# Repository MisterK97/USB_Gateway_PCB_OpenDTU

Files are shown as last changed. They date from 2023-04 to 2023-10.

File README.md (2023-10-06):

# USB-Gateway-Platine für z.B. OpenDTU auf ESP32-Basis

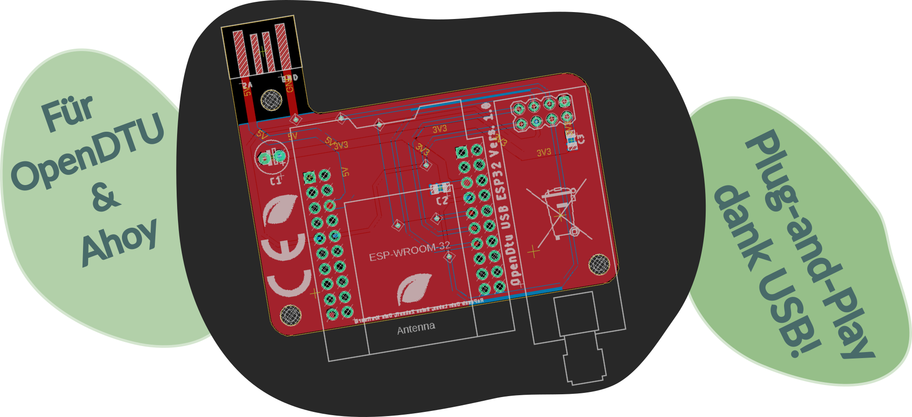
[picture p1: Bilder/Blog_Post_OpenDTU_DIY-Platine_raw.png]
Layout der USB-Gateway-Platine


In diesem Repo werden die Unterlagen und Dateien zum USB-Gateway abgelegt.

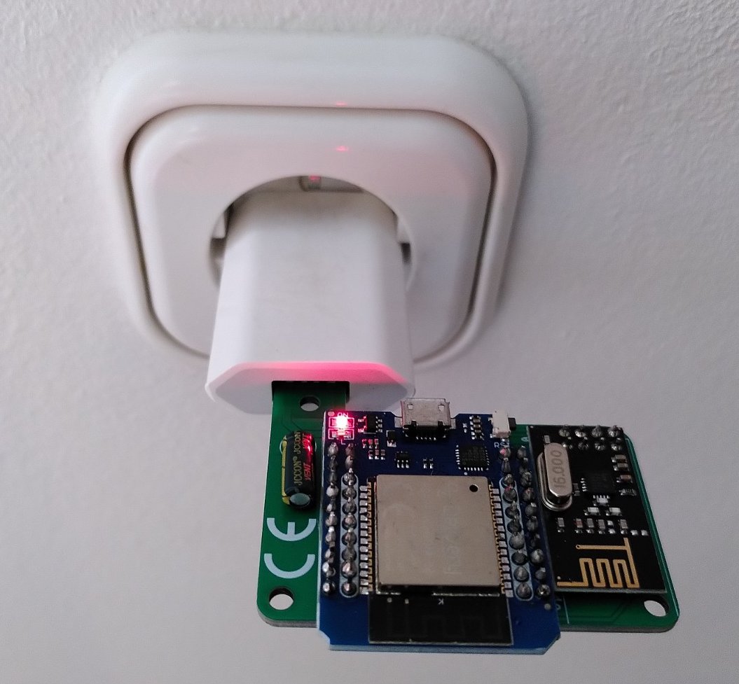
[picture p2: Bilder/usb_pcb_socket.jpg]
USB-Gateway-Platine in Steckdose

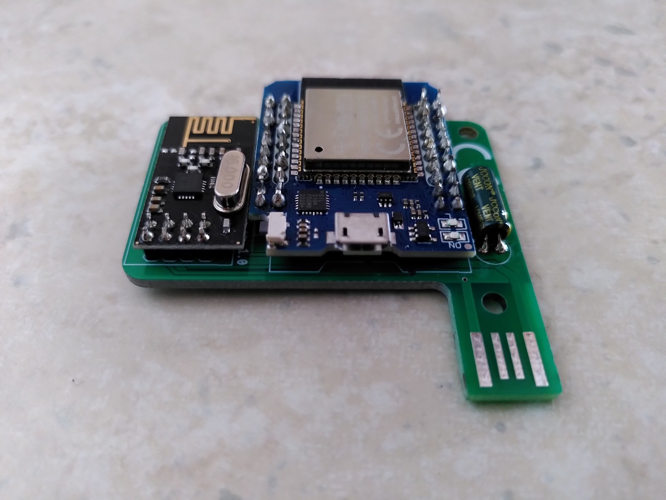
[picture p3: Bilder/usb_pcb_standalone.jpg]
USB-Gateway-Platine


Die Platine wurde mit Eagle entworfen und auf Basis des Schaltplans der Github-Page von OpenDTU (<https://github.com/tbnobody/OpenDTU>) erstellt.
Mit der besonderen Form der Platine kann das Gateway direkt über ein USB-Netzteil versorgt werden und benötigt daher kein Kabel oder eine zusätzliche Befestigung.

Wenn man die Platine fertigt gelötet hat und den ESP32 mit OpenDTU geflasht hat, müssen keine zusätzlichen Einstellungen bezüglich der GPIOs vorgenommen werden.
Die Pin-Belegung entspricht der Standardbelegung von OpenDTU.

**Schaltplan-Ausschnitt und Layout:**
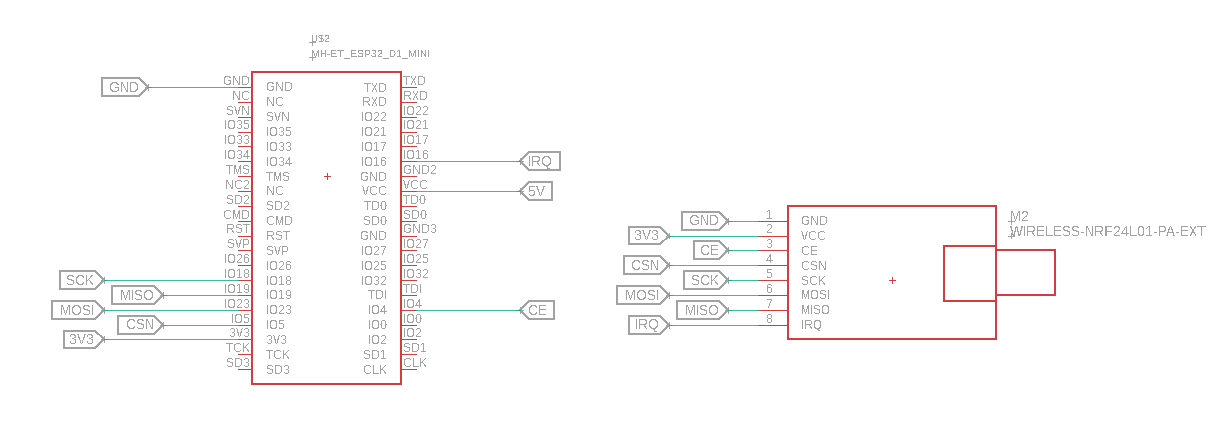
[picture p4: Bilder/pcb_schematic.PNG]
USB-Gateway-Schaltplan

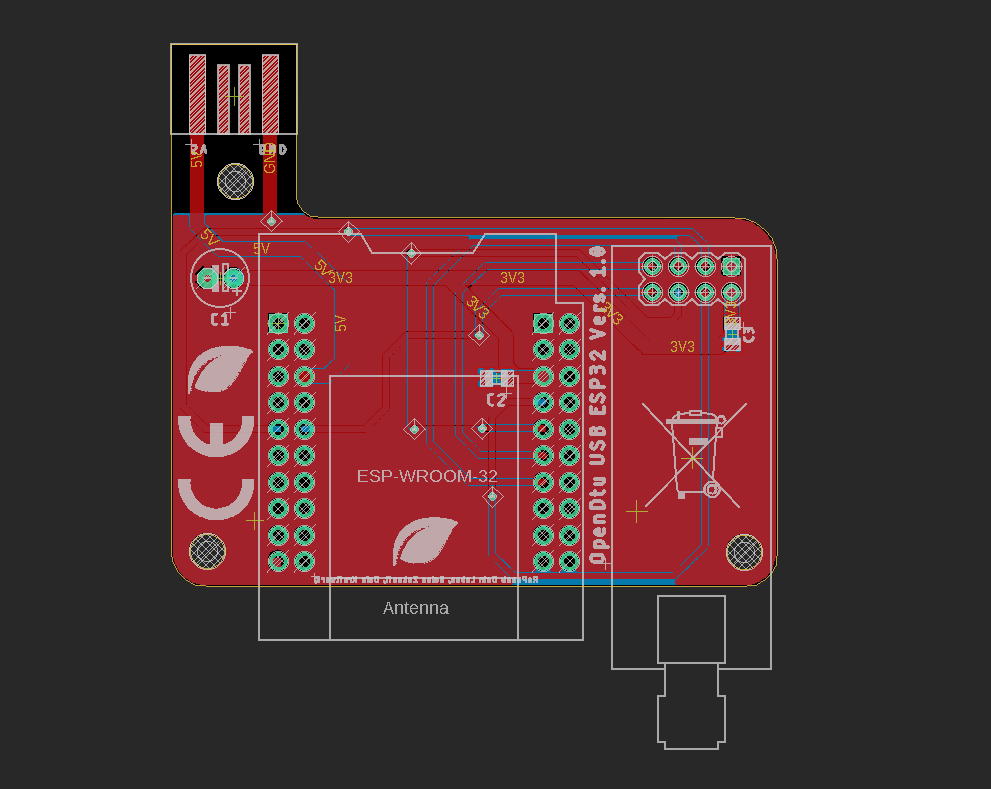
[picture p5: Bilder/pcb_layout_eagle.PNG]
USB-Gateway-Layout


**Benötigte Komponenten:**
- USB-Platine (siehe Dateien)
- ESP32 D1 MINI (<https://www.azdelivery.de/products/esp32-d1-mini>)
- NRF24L01 (<https://www.azdelivery.de/products/3x-nrf24l01-mit-2-4-ghz>)

Diese Repo hat nichts mit der OpenDTU-Repo (<https://github.com/tbnobody/OpenDTU>) zu tun und steht in keiner Absprache mit den Entwickler*innen. Danke für die tolle Arbeit der Community! Ich hoffe meine kleine Platine hilft euch!

Die Verwendung der gezeigten Platine bzw. des Schaltplanes erfolgt auf eigenes Risiko und ohne jegliche Gewährleistung!

Viel Spaß beim Modifizieren und Basteln! :)

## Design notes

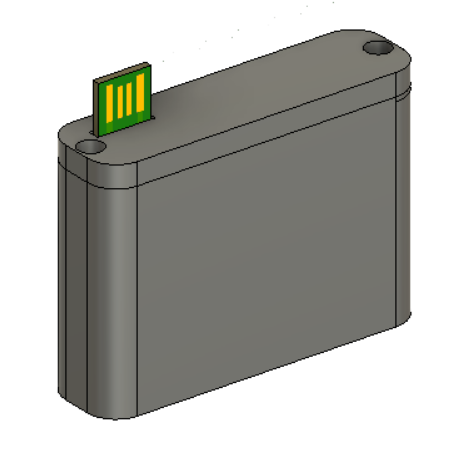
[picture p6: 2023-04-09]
Bilder/pcb_case_fusion360.PNG

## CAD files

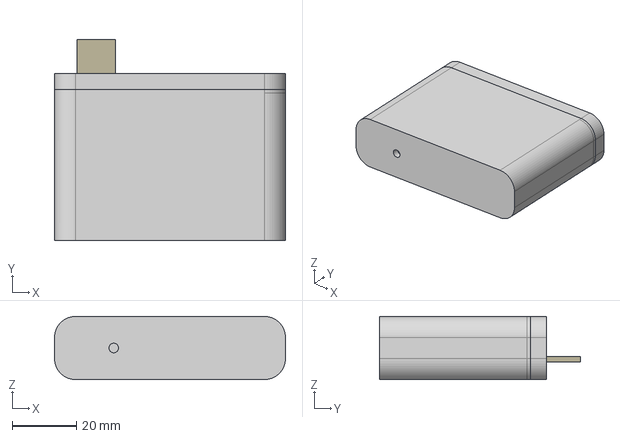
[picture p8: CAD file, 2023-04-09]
CAD/USB-Gateway_Case.step
72.1 x 62.8 x 19.7 mm

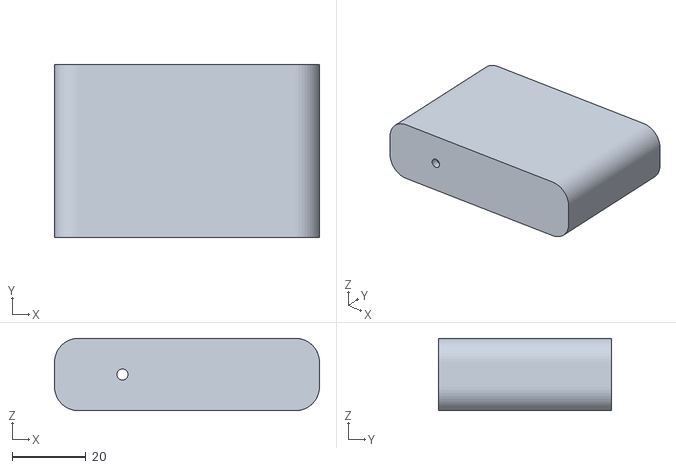
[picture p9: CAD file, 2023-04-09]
CAD/USB-Gateway_Case_Bottom.stl
72.1 x 47.2 x 19.7

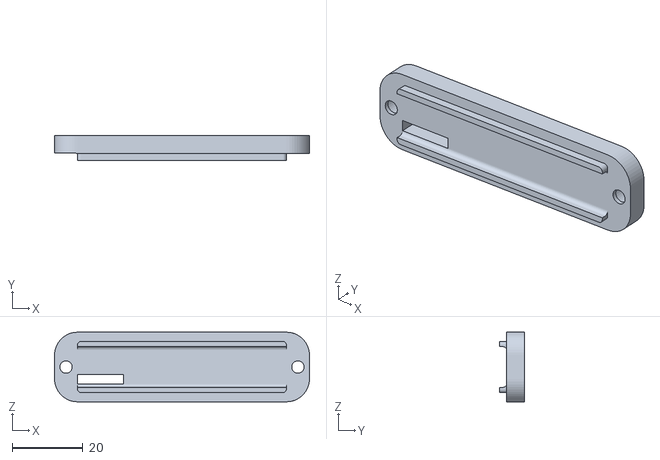
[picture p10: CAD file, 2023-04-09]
CAD/USB-Gateway_Case_Top.stl
72.0 x 7.04 x 19.7

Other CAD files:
CAD/USB-Gateway_Case.f3z

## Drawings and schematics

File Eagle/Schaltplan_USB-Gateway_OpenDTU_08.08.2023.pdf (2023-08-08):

A

A

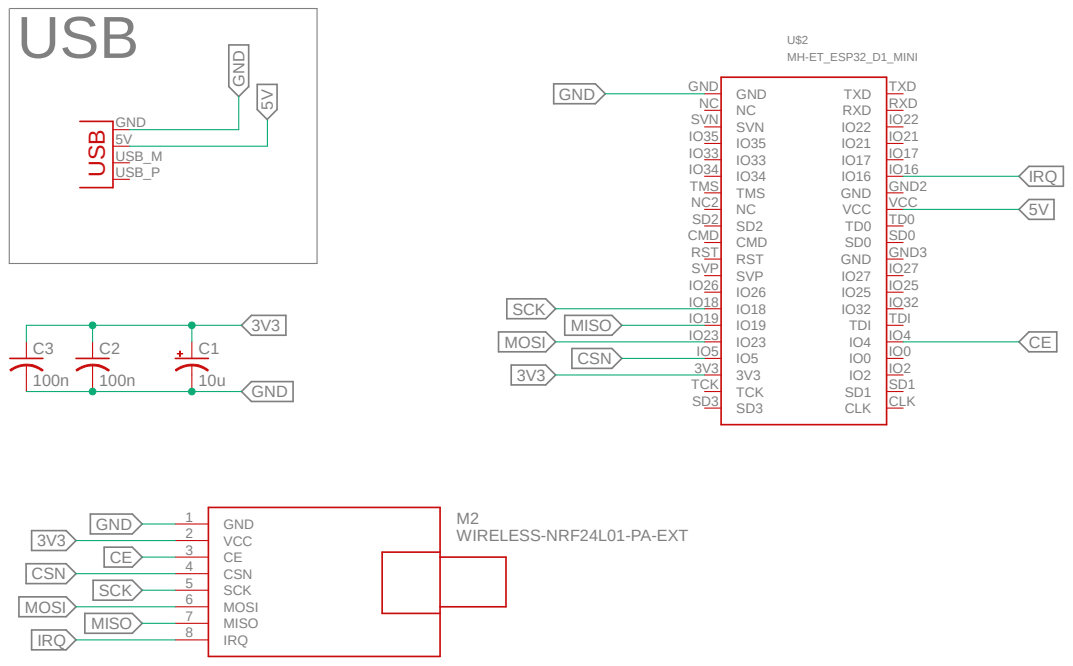
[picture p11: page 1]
USB; MH-ET_ESP32_D1_MINI; USB_P; USB_M; GND; GND GND NC NC SVN SVN IO35 IO35 IO33 IO33 IO34 IO34 TMS TMS NC NC2 SD2 SD2 CMD CMD RST RST SVP SVP IO26 IO26 IO18 IO18 IO19 IO19 IO23 IO23 IO5 IO5 3V3 3V3 TCK TCK SD3 SD3; TXD; RXD; GND2; VCC; GND3; TDI; CLK; GND 1 VCC 2 CE 3 CSN 4 SCK 5 MOSI 6 MISO 7; IRQ 8; GND⁵V; CSN; SCK; MOSI; MISO; IRQ USB; IRQ

WIRELESS-NRF24L01-PA-EXT

08.08.2023 10:20 C:\Users\Wayne\Documents\GitHub\USB-Gateway_OpenDTU\Eagle\OpenDTU_USB.sch (Sheet: 1/1)

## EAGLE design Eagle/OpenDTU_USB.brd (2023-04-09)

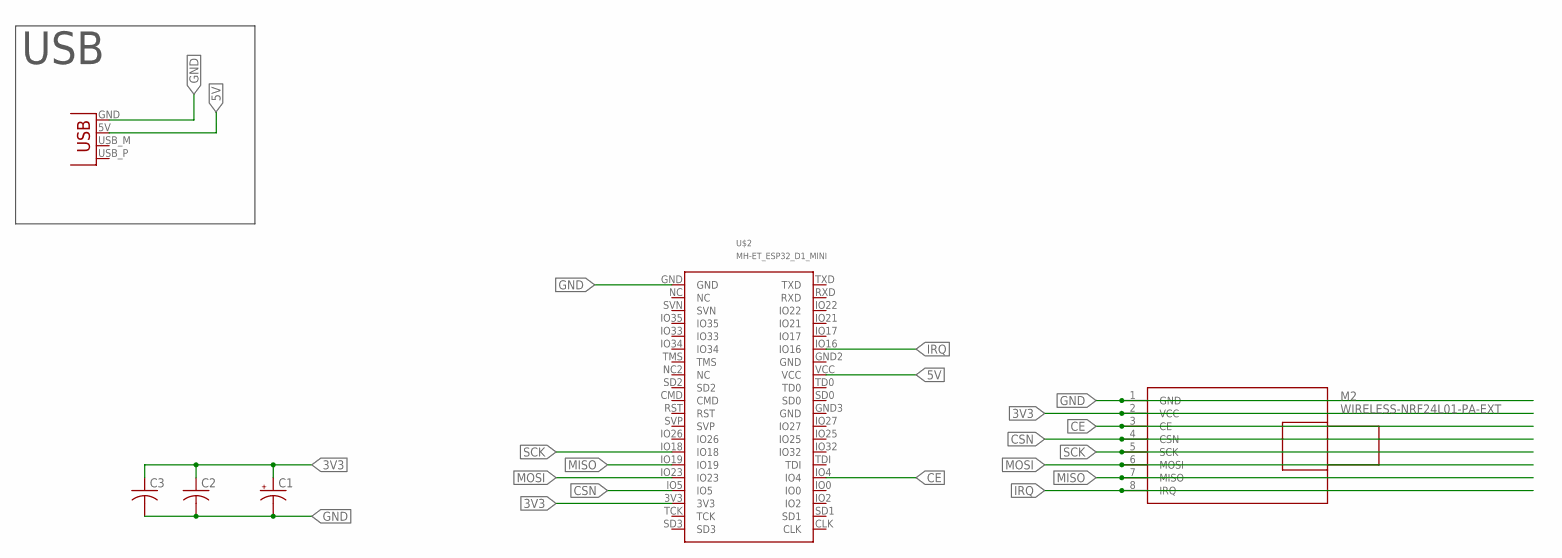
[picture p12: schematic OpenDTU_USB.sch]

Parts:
C1: CPOL-USE2.5-6; E2,5-6
C2, C3: C-USC0805K; C0805K
M2: WIRELESS-NRF24L01-PA-EXT
U$2: MH-ET_ESP32_D1_MINI
X1: USBPCB; USB-A-PCB

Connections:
3V3: C1.+, C2.1, C3.1, M2.2 (VCC), U$2.3V3
5V: U$2.VCC, X1.5V (VBUS)
CE: M2.3 (CE), U$2.IO4
CSN: M2.4 (CSN), U$2.IO5
GND: C1.-, C2.2, C3.2, M2.1 (GND), U$2.GND, X1.GND
IRQ: M2.8 (IRQ), U$2.IO16
MISO: M2.7 (MISO), U$2.IO19
MOSI: M2.6 (MOSI), U$2.IO23
SCK: M2.5 (SCK), U$2.IO18

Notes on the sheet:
USB

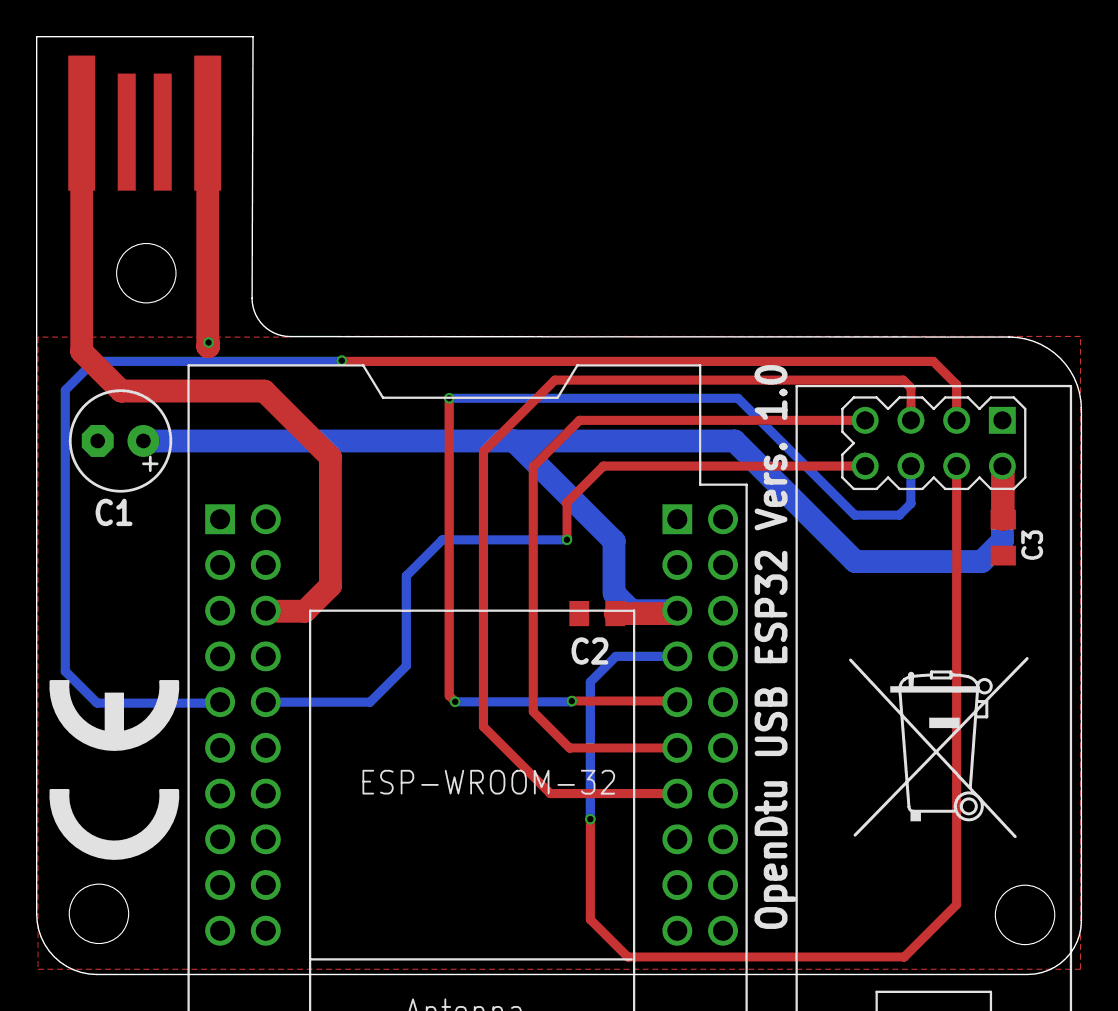
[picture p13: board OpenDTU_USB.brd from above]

Board: 2 copper layers, 58.0 x 52.1 mm, 8 parts (0 on the bottom side), 9 nets.

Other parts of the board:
U$1: CE_7.3MM
U$3: MUELLTONNE_10.00

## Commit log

2023-04-09 bilder hinzugefügt
    [OpenDTU_USB.brd, OpenDTU_USB.sch, USB-Gateway_Case.f3z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]
2023-08-08 Bilder und Schaltplan erneuert
2023-10-06 Schraubklemme hinzugefügt, Empfang verbessert, USB wegbrechbar
    [OpenDTU_USB.sch]

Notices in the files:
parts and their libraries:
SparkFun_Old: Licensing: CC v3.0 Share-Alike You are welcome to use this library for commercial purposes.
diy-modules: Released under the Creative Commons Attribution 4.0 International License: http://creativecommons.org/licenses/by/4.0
